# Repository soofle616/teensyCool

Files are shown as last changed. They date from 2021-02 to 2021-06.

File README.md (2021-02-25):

# teensyCool
Code, mechanical, and electrical design files for teensyCool automatic adjustable coolant nozzle for Tormach milling machines

This repository contains files to recreate the teensyCool by SmellyDog automatic adjustable coolant nozzle for Tormach milling machines. This project replicates the function and largely recreates the aesthetic of the SmartCool adjustable coolant nozzle available from Tormach. Additional information and installation instructions will periodically be added to this README as time permits. 

Programming the teensy can be accomplished using Teensyduino within the Arduino IDE: https://www.pjrc.com/teensy/td_download.html

Installation on a Tormach mill requires installation of 99-teensy.rules to /etc/udev/rules in PathPilot.

Thanks to Jon Watte for his serial parsing routine used in his USBIO emulator found here: https://github.com/jwatte/teensy_tormach_usbio

All files and designs are Copyright 2021 Ian Vivero, released under GNU GPLV3.0

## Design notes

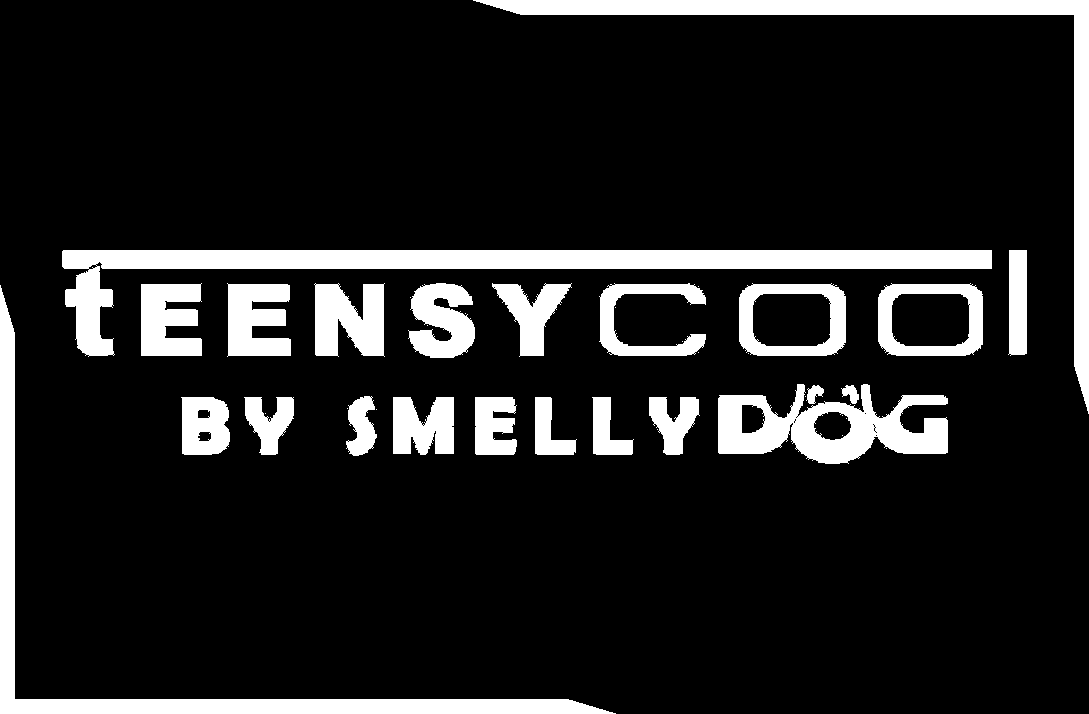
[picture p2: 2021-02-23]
Artwork/teensycool controller label.png

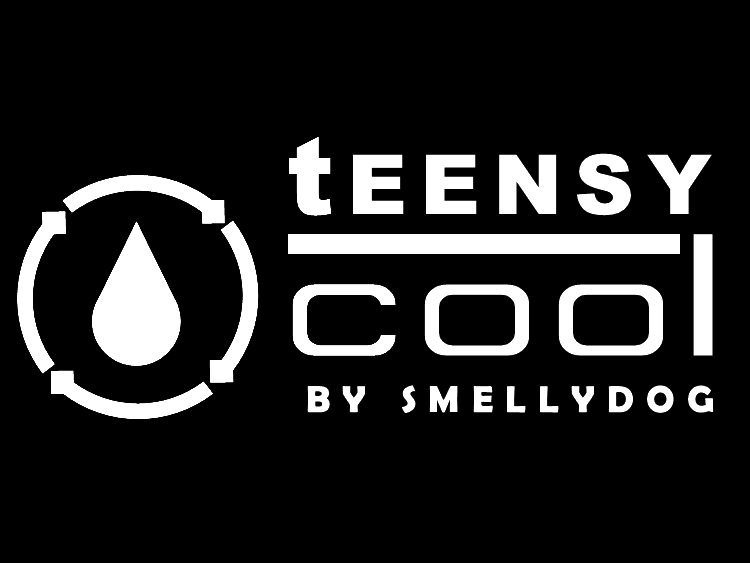
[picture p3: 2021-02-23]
Artwork/teensyCool housing label.png

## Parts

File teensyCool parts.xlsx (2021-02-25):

link | desc
https://www.amazon.com/gp/product/B00ON8XFSO | solenoid
https://www.amazon.com/gp/product/B015QUPO5Y/ref=ppx_yo_dt_b_asin_title_o00_s00?ie=UTF8&psc=1 | teensy 3.2
https://www.amazon.com/gp/product/B0833WYLWQ/ref=ppx_yo_dt_b_asin_title_o02_s00?ie=UTF8&psc=1 | audio jack 2pack
https://www.amazon.com/gp/product/B083TF4K6L/ref=ppx_yo_dt_b_asin_title_o03_s01?ie=UTF8&psc=1 | 2n7000
https://www.amazon.com/gp/product/B077D79743/ref=ppx_yo_dt_b_asin_title_o08_s00?ie=UTF8&psc=1 | audio plug 6 pack
https://www.amazon.com/gp/product/B07TJFG1H5/ref=ppx_yo_dt_b_asin_title_o09_s00?ie=UTF8&psc=1 | 3 conductor 20ga wire
https://www.amazon.com/dp/B01GNORMWA | 30A mosfet
https://www.amazon.com/gp/product/B07Y8MFCJD/ref=ppx_yo_dt_b_asin_title_o00_s00?ie=UTF8&psc=1 | power jack
https://www.amazon.com/gp/product/B01GD4ZQRS/ref=ppx_yo_dt_b_asin_title_o01_s00?ie=UTF8&psc=1 | power adapter
https://www.amazon.com/JOBKIM-Braided-Charging-Motorola-Smartphones/dp/B08LGFC5HB | usb cable
https://www.amazon.com/DYNAMIXEL-902-0003-001-AX-12A/dp/B0051OXJXU | servo
https://www.amazon.com/EDGELEC-Resistor-Tolerance-Resistance-Optional/dp/B07HDGX5LM?s=industrial | 10k Ohm resistor
https://www.amazon.com/MIC-Silastic-Junction-Standard-Rectifier/dp/B00W17LOBO?s=industrial | 1n4007 diode
https://www.amazon.com/uxcell-Screw-Terminal-Block-3-5mm/dp/B01C3DGIBQ | 2pos screw terminal
https://www.amazon.com/DIYhz-green-Terminal-Connector-Arduino/dp/B07B79Q911 | 3pos screw terminal
https://www.mcmaster.com/catalog/5779K109 | 1/4" ptc fitting
https://www.mcmaster.com/catalog/127/52 | brass elbow
https://www.mcmaster.com/catalog/127/47 | brass nipple
https://www.mcmaster.com/catalog/127/52 | brass tee
https://www.mcmaster.com/catalog/127/178 | 1/4" ss pipe 4"
https://www.mcmaster.com/catalog/127/178 | 3/16 ss pipe 4"
https://www.mcmaster.com/catalog/127/3241 | 4-40 x 5/16 ss screw
https://www.mcmaster.com/catalog/127/3241 | 4-40 x 1/8 ss screw
https://www.mcmaster.com/catalog/127/3363 | 4-40 x 2-1/4 ss screw
https://www.mcmaster.com/catalog/127/962 | cord grip
https://www.mcmaster.com/catalog/127/238 | 3/8 ptc fitting
https://www.mcmaster.com/catalog/127/166 | 3/8 clear tube
https://www.mcmaster.com/catalog/127/166 | 1/4 clear tube
https://www.mcmaster.com/catalog/127/3762 | magnet
https://www.mcmaster.com/catalog/127/4050 | ss plate for bracket
https://www.mcmaster.com/screws/socket-head-screws/system-of-measurement~metric/thread-size~m2/material~stainless-steel/material~18-8-stainless-steel/ | M2 SHCS
https://www.mcmaster.com/92196A106/ | 4-40 ss SHCS

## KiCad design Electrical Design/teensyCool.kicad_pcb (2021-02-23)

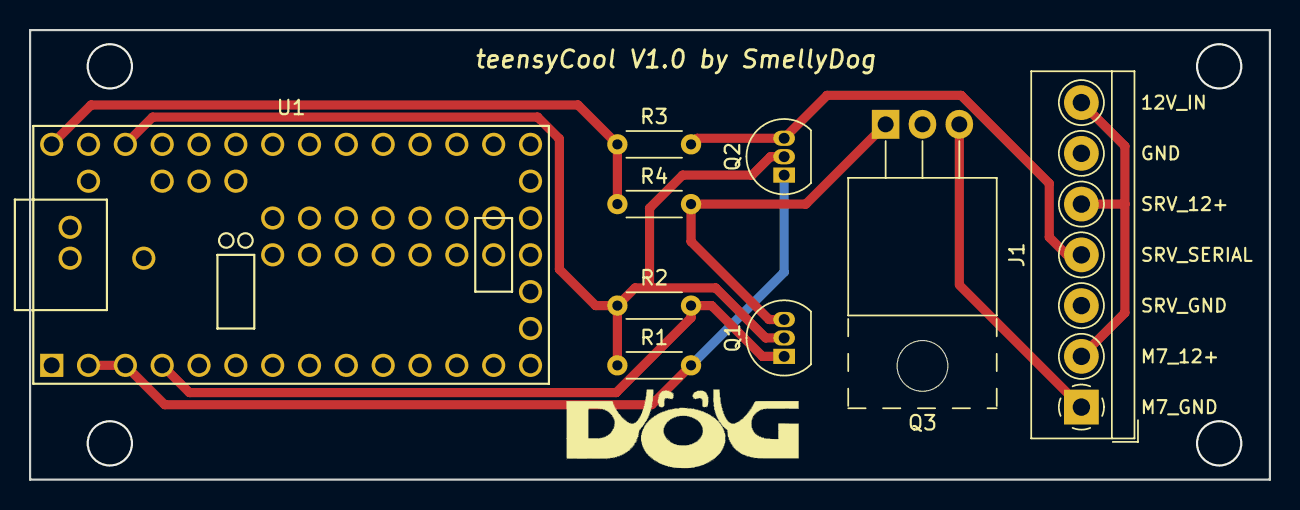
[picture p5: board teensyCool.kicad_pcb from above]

Board: 2 copper layers, 85.5 x 31.0 mm, 9 parts (0 on the bottom side), 9 nets.

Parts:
J1: Screw_Terminal_01x07; TerminalBlock_4Ucon_1x07_P3.50mm_Horizontal
Q1, Q2: 2N7000; TO-92_Inline
Q3: RFP30N06LE; TO-220-3_Horizontal_TabUp
R1, R2, R3, R4: 10k; R_Axial_DIN0204_L3.6mm_D1.6mm_P5.08mm_Horizontal
U1: Teensy3.2; Teensy30_31_32_All_Pins

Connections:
/3.3V: Q1.2, Q2.2, R1.1, R2.1, U1.31
/5V: R3.1, R4.1, U1.33
/12V: J1.2, J1.5, J1.7
GND: J1.3, J1.6, Q3.2, U1.1
unnamed: J1.1, Q3.3
unnamed: J1.4, Q2.3, R3.2
unnamed: Q1.1, R2.2, U1.4
unnamed: Q1.3, Q3.1, R4.2
unnamed: Q2.1, R1.2, U1.2, U1.3

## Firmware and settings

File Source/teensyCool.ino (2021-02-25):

#include "Dynamixel.h"
#include "DynamixelInterface.h"
#include "DynamixelMotor.h"

#define LED_PIN 13
#define RELAY_PIN 2
#define VERSION_STR "Z-Bot SCHNOZZ teensyCool by SmellyDog v1.0"
#define COMMAND_RESP ".\r\n"
#define DEBUG 0

char inbuf[256];
uint8_t iptr;
bool led;

void setup() {
  pinMode(LED_PIN, OUTPUT);
  pinMode(RELAY_PIN, OUTPUT);
  #ifdef DEBUG
    Serial2.begin(9600);
  #endif
}

void loop() {

  DynamixelInterface dInterface(Serial1); // Stream
  dInterface.begin(1000000, 50); // baudrate, timeout
  DynamixelMotor motor(dInterface, 1);  // Interface , ID

  motor.init(); // This will get the returnStatusLevel of the servo
  motor.jointMode(); // Set the angular limits of the servo. Set to [min, max] by default
  motor.enableTorque();
  
  int n = Serial.available();
  //  Parse whatever we have -- which may be partial lines, so keep buffer
  while (n > 0) {
    --n;
    int ch = Serial.read();
    if (ch == '\r' || ch == '\n') { //Terminate the buffer when an \r or \n is received
      if (iptr > 0) {
        if (inbuf[0] == 'V' && inbuf[1] == 'E') { //Mill will send "VE" to initiate comms with smartcool
          Serial.write(VERSION_STR);  //Mill expects Z-Bot SCHNOZZ in response
          #ifdef DEBUG
            Serial2.println("VE received, response sent");
          #endif
        } else if (inbuf[0] == 'W') { //Servo position and parameter commands begin with "W"
          if (iptr < 14) {
            //  bad CMD!
          } else { //Parse servo command
            //TODO, add parsing code
            int cmdType = 10*(inbuf[8] - '0') + (inbuf[9] - '0'); //This will convert the ASCII values of each sent digit to a single int value
            int cmdContent = 1000*(inbuf[10] - '0') + 100*(inbuf[11] - '0') + 10*(inbuf[12] - '0') + (inbuf[13] - '0');
            switch (cmdType) {
              case 34:  //Mill is sending a torque limit setting
              #ifdef DEBUG
                Serial2.println("Torque command received");
              #endif
                //TODO: relay torque limit paramter to servo
                break;
              case 16:  //Mill is sending a servo response setting
              #ifdef DEBUG
                Serial2.println("Servo response command received");
              #endif
                //TODO: relay servo response parameter to servo
                break;
              case 26:  //Mill is sending a CW compliance setting
              #ifdef DEBUG
                Serial2.println("CW Compliance command received");
              #endif
                //TODO: relay CW compliance paramter to servo
                break;
              case 27:  //Mill is sending a CCW compliance setting
              #ifdef DEBUG
                Serial2.println("CCW Compliance command received");
              #endif
                //TODO: relay CCW compliance paramter to servo
                break;
              case 28:  //Mill is sending CW slope setting
              #ifdef DEBUG
                Serial2.println("CW Slope command received");
              #endif
                //TODO: relay CW slope parameter to servo
                break;
              case 29:  //Mill is sending CCW slope setting
              #ifdef DEBUG
                Serial2.println("CCW slope command received");
              #endif
                //TODO: relay CCW slope parameter to servo
                break;
              case 48:  //Mill is sending punch current setting
              #ifdef DEBUG
                Serial2.println("Punch current command received");
              #endif
                //TODO: relay punch current setting to servo
                break;
              case 30:  //Mill is sending servo position command
              #ifdef DEBUG
                Serial2.print("Position command received. New position: ");
                Serial2.println(cmdContent);
              #endif
                motor.goalPosition(cmdContent); //Command servo move
                break;
            }
            Serial.write(COMMAND_RESP);
          }
        } else if (inbuf[0] == '2') { //Relay2 commands begin with a 2
          if (iptr < 2) {
            // bad CMD;
          } else { //Parse relay 2 command
            if (inbuf[1] == '+') {  //Mill has commanded Relay2 On
              digitalWrite(LED_PIN, HIGH);
              digitalWrite(RELAY_PIN, HIGH);
            } else {  //Mill has commanded Relay2 Off
              digitalWrite(LED_PIN, LOW);
              digitalWrite(RELAY_PIN, LOW);
            }
            inbuf[iptr] = 0;
            Serial.write(COMMAND_RESP);
          }
        } else {
          //  bad CMD!!
        }
      }
      memset(inbuf, 0, iptr);
      iptr = 0;
    } else  {
      if (iptr == sizeof(inbuf)-1) {
        //  OVERFLOW!
        iptr = 0;
      } else {
        inbuf[iptr++] = ch;
      }
    }
  }
}

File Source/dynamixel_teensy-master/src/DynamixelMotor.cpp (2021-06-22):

#include "DynamixelMotor.h"

DynamixelDevice::DynamixelDevice(DynamixelInterface &aInterface, DynamixelID aID):
	mInterface(aInterface), mStatusReturnLevel(255), mID(aID)
{
	mStatus = DYN_STATUS_OK;
	if (mID == BROADCAST_ID)
	{
		mStatusReturnLevel = 0;
	}
}

uint8_t DynamixelDevice::statusReturnLevel()
{
	if (mStatusReturnLevel == 255)
	{
		init();
	}
	return mStatusReturnLevel;
}

void DynamixelDevice::statusReturnLevel(uint8_t aSRL)
{
	write(DYN_ADDRESS_SRL, aSRL);
	if (status() == DYN_STATUS_OK)
	{
		mStatusReturnLevel = aSRL;
	}
}

uint16_t DynamixelDevice::model()
{
	uint16_t result;
	read(DYN_ADDRESS_ID, result);
	return result;
}

uint8_t DynamixelDevice::firmware()
{
	uint8_t result;
	read(DYN_ADDRESS_FIRMWARE, result);
	return result;
}

void DynamixelDevice::communicationSpeed(uint32_t aSpeed)
{
	uint8_t value = 2000000 / aSpeed - 1;
	if (value != 0) // forbid 2MBd rate, because it is out of spec, and can be difficult to undo
	{
		write(DYN_ADDRESS_BAUDRATE, value);
	}
}

DynamixelStatus DynamixelDevice::init()
{
	mStatusReturnLevel = 1;
	DynamixelStatus status = ping();
	if (status != DYN_STATUS_OK)
	{
		mStatusReturnLevel = 0;
		return status;
	}
	status = read(DYN_ADDRESS_SRL, mStatusReturnLevel);
	if (status & (DYN_STATUS_COM_ERROR | DYN_STATUS_TIMEOUT))
	{
		mStatusReturnLevel = 0;
	}
	else if (status != DYN_STATUS_OK)
	{
		mStatusReturnLevel = 0;
		return status;
	}
	return DYN_STATUS_OK;
}



DynamixelMotor::DynamixelMotor(DynamixelInterface &aInterface, DynamixelID aId):
	DynamixelDevice(aInterface, aId)
{}


void DynamixelMotor::wheelMode()
{
	jointMode(0,0);
}

void DynamixelMotor::jointMode(uint16_t aCWLimit, uint16_t aCCWLimit)
{
	uint32_t data = (aCWLimit | (uint32_t(aCCWLimit) << 16));
	write(DYN_ADDRESS_CW_LIMIT, data);
}

void DynamixelMotor::enableTorque(bool aTorque)
{
	write(DYN_ADDRESS_ENABLE_TORQUE, uint8_t(aTorque?1:0));
}

DynamixelStatus DynamixelMotor::alarmShutdown(uint8_t aMode)
{
	aMode &= B01111111;
	return write(DYN_ADDRESS_ALARM_SHUTDOWN, aMode);
}

DynamixelStatus DynamixelMotor::speed(uint16_t aSpeed)
{
	return write(DYN_ADDRESS_GOAL_SPEED, aSpeed);
}

DynamixelStatus DynamixelMotor::torqueLimit(uint16_t aTorque)
{
	return write(DYN_ADDRESS_TORQUE_LIMIT, aTorque);
}

DynamixelStatus DynamixelMotor::goalPosition(uint16_t aPosition)
{
	return write(DYN_ADDRESS_GOAL_POSITION, aPosition);
}

DynamixelStatus DynamixelMotor::goalPositionDegree(uint16_t posDeg)
{
	return goalPosition(posDeg * 3.41);
}

void DynamixelMotor::recoverTorque()
{
	uint16_t currentPosition = -1;
	if (!(read(DYN_ADDRESS_CURRENT_POSITION, currentPosition) & DYN_STATUS_COM_ERROR))
	{
		if (currentPosition != (uint16_t)-1)
		{
			write(DYN_ADDRESS_GOAL_POSITION, currentPosition);
		}
	}

	uint16_t torque = 0x3FF;
	if (read(DYN_ADDRESS_MAX_TORQUE, torque) & DYN_STATUS_COM_ERROR)
	{
		write(DYN_ADDRESS_TORQUE_LIMIT, 0x3FF);
	}
	else
	{
		write(DYN_ADDRESS_TORQUE_LIMIT, torque);
	}
	enableTorque();
}

DynamixelStatus DynamixelMotor::resetSecuritySettings()
{
	DynamixelStatus status = 0;
	status |= write(DYN_ADDRESS_TEMP_LIMIT, (uint8_t)85);
	status |= write(DYN_ADDRESS_LOW_VOLTAGE_LIMIT, (uint8_t)60);
	status |= write(DYN_ADDRESS_HIGH_VOLTAGE_LIMIT, (uint8_t)140);
	status |= write(DYN_ADDRESS_MAX_TORQUE, (uint16_t)0x3FF);
	status |= write(DYN_ADDRESS_ALARM_LED, (uint8_t)36);
	status |= write(DYN_ADDRESS_ALARM_SHUTDOWN, (uint8_t)36);
	return status;
}

void DynamixelMotor::setId(uint8_t newId)
{
	write(DYN_ADDRESS_ID, newId);
	mID = newId;
}

void DynamixelMotor::led(uint8_t aState)
{
	write(DYN_ADDRESS_LED, aState);
}

DynamixelStatus DynamixelMotor::currentPosition(uint16_t &aPosition)
{
    aPosition = UINT16_MAX;
    return read(DYN_ADDRESS_CURRENT_POSITION, aPosition);
}

DynamixelStatus DynamixelMotor::currentPositionDegree(uint16_t &aPosition)
{
    DynamixelStatus status = currentPosition(aPosition);
    aPosition = (uint16_t)((float)aPosition / 3.41);
	return status;
}

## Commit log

2021-02-25 Add files via upload
    Source code, KiCad design files and label graphics uploaded
    [teensyCool.kicad_pcb, teensyCool.sch]
2021-06-22 Add dynamixel library
    Add arduino library files for dynamixel library to control the servo. Source/Author of library unknown
    [controltable.ods]
